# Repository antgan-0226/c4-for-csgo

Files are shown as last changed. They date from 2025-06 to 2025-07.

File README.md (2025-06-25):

# c4-for-csgo
A CSGO game C4 bomb model based on stm32.

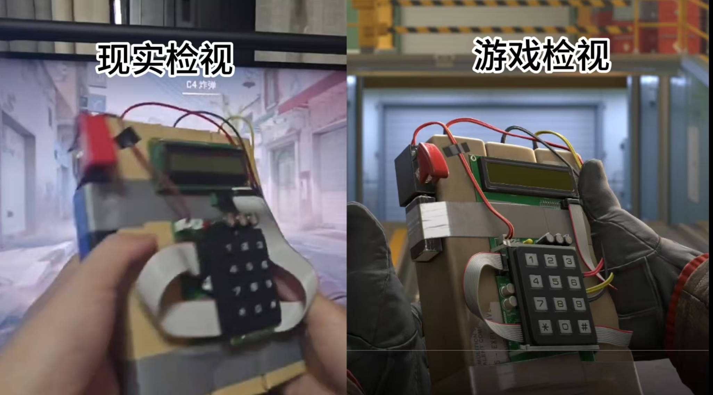
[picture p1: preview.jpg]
preview picture


**主要功能**

- 密码部署：玩家需要输入正确的密码7355608来部署 C4 炸弹，若密码错误会有相应的提示。
- 倒计时与解锁：炸弹部署成功后，开始倒计时，在倒计时期间玩家可以尝试输入解锁密码来拆除炸弹。
- 音效播放：配备 TF 卡音乐盒，在不同的状态下播放相应的音效，如部署音效、爆炸音效、MVP 音乐等。
- 状态显示：通过 LCD 屏幕显示当前的状态信息，如密码输入提示、倒计时信息、胜利提示等。
- 闹钟模式：通过按下特定按键（# 键）可进入闹钟模式。（正在做）

**免责声明:**
本项目仅为模型，不包含爆炸功能，任何改装等均不在本项目范畴中。本项目亦在还原CS2中C4炸弹的外观而非实际用途。

# 环境
- 使用Keil5环境开发stm32f103c8t6

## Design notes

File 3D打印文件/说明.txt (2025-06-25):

3D打印填充物3个190 * 40 * 43mm(长宽高)

如果你没有3D打印机，可以找我  或者找闲鱼的3D打印代打服务，给卖家说明填充10~15%即可，性价比最高
或者寻找其他方案

不要去淘宝拼夕夕找3D打印啊啊啊啊啊啊啊啊啊，60起步会被坑很多钱

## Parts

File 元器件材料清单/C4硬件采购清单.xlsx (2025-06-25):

采购价格仅供参考，具体不同店价格不一样。 整体元器件成本大概是100~120之间。如果要买其他电烙铁等工具，总成本在300左右。 如果没时间做，可以加微信: mayijun0226 可以帮忙代工，保姆级详细教程正在做，有疑问可以加微信询问。
器件 | 数量 |  | 备注 | 淘宝店家 | 价格
9V充电锂电池500mA | 1 |  | 不要用碳性电池或碱性电池！！ | 何维克电池 | 6.9
9V电池扣I型硬扣 | 1 | =DISPIMG("ID_F30DDC7D537947F4BAE9905A0A8C0E81",1) |  | zave | 3.02
3362电位器10K | 1 | =DISPIMG("ID_8B0D3E154CCE463D918A6B754BDE80D5",1) |  | zave | 3.68
NPN三极管s8050 | 2 | =DISPIMG("ID_EE3C3700D55947208426E54390F3B294",1) |  | zave | 4.11
简易牛角插座2.54mm 2*8p直针 | 1 | =DISPIMG("ID_3D62FF74ED64414888F32AC91180FFE2",1) |  | zave | 2.35
铝电解电容直插 2200uf | 3 | =DISPIMG("ID_F6F344BF5B464863AC43FE94093CC294",1) |  | zave | 3.69
XH2.54mm直针插座2P | 2 | =DISPIMG("ID_A2CB149D019C4AB29669064B79B3C5D3",1) |  | zave | 2.44
XH2.54mm排线2p30cm公头 | 2 | =DISPIMG("ID_4477A8D5127242539B20EBAD8990196A",1) | 实际用下来30cm有点长了，可以买15cm的 | zave | 3.53
有源蜂鸣器5v D=12mm | 1 | =DISPIMG("ID_0D7D1331BE1E4B7FA3E4765643F8FA4A",1) |  | zave | 2.82
HK-4100F-DC5V汇科继电器 | 1 | =DISPIMG("ID_3BB9316D591745199AFCEB55EA78C735",1) |  | zave | 3.53
KF310-4P接线柱 十字 蓝色 可拼接 | 1 | =DISPIMG("ID_3EF6C32E9268451F9E2B2C28B976A1E8",1) |  | zave | 3.92
排针2.54mm 1*9P 针长19~23mm均可 | 1 | =DISPIMG("ID_BE62D8DB6DDB46B385E3519C7CAB37A6",1) | 建议针长19~23mm，主包是21的刚刚好 | zave | 4.91
5mm圆头LED直插红色 | 1 | =DISPIMG("ID_A6C1ED3964644E9C8F6AD8B1F987F005",1) |  | zave | 5.49
220欧姆金属膜电阻 （用于led限流） | 1 |  |  | risym 旗舰店 | 2.27
10k欧姆金属膜电阻（用于三极管下拉) | 1 |  | 跟上面那个电阻在同一个链接，你可以替换成贴片的，改原理图和pcb即可 | risym 旗舰店 | 2.27
8Ω1W或8Ω2W喇叭（直径最好<30mm） | 1 | =DISPIMG("ID_752ABEF71A3C4457934C7B5C5D347EE7",1) |  | zave | 3.45
LED显示屏排线 16P 30cm | 1 |  |  | 欣薇电子科技 | 1.08
电缆0.5平方纯铜（红黑黄） | 1 |  |  | 利民达电线电缆 | 3.15
STM32F103C8T6开发板 | 1 |  | 注意焊接的左右方向 | 贝科姆旗舰店 | 6.75
ST-LINK | 1 |  |  | 深圳市轩特佳电子 | 8.8
单片机矩阵键盘3*4 | 1 |  |  | 欣薇电子科技 | 6.28
任意5v稳压模块 | 1 |  |  | 欣薇电子科技 | 1.85
mini mp3 player模块 | 1 |  |  | 捷兴泰电子 | 3.83
钮子开关 开关+大红盖 | 1 |  |  | 深圳市辉泰电器 | 7.5
LCD1601a(黄绿色) | 1 | =DISPIMG("ID_F51466F975EA4189BC218596CA256447",1) | 不要买错成1602 | 上海斯迈诺 | 5.5
银灰色PVC警示胶带 | 1 |  |  | 品尚美塑旗舰店 | 5.1
黑色PVC胶布 | 1 |  |  | 品尚美塑旗舰店 | 3.95
A4牛皮纸浅色 | 1 |  | 浅色，A4，裁切尺寸见表的最下面附录 | 书昶办公用品专营店 | 6.46
热熔胶枪 | 1 | 随便买便宜的就行 | 买便宜的，附赠胶棒最好多于5根，我用掉了五根 |  | 15.59
小容量TF卡 | 1 | =DISPIMG("ID_F34BEDC7FAAB4E029C26E063471F7568",1) |  | 森秀 | 4.99
各类焊接工具：电烙铁、焊锡丝、等等 | 1 | =DISPIMG("ID_72A3BAE1297947FE8F4B7105E580A8AE",1) |  | 德力西 | 170
 |  |  |  | 仅元器件消耗品成本（不包括工具电烙铁等） | 123.62
 |  |  |  | 总计（包含工具） | 309.21

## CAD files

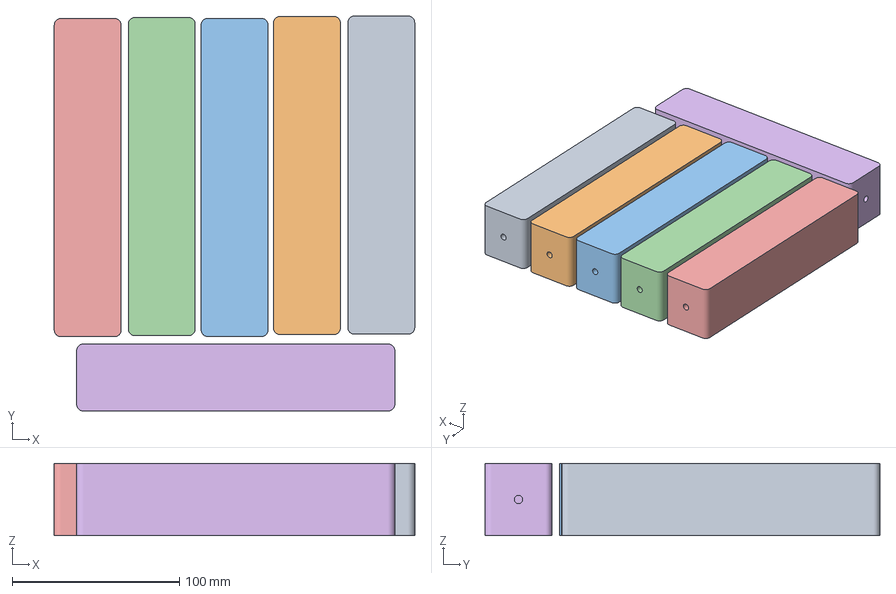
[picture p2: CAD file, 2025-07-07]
3D打印文件/c4填充物.3mf
215.3 x 235.8 x 43.0 mm
c4填充物.STL x 6

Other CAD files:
3D打印文件/c4填充物.STL

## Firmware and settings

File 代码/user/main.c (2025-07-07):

#include "stm32f10x.h"
#include "stm32f10x_flash.h"
#include "matrixkey.h"
#include "1602a.h"
#include "delay.h"
#include "LED.H"
#include "math.h"
#include "TIMER.h"
#include "Serial.h"
#include "mp3.h"
#include "string.h"
#include <stdbool.h>
#include <stdio.h> 


//函数声明
void showDefaultScreen(void);//展示默认屏幕
char arraysEqual(unsigned char arr1[], unsigned char arr2[], int size); //比较数组
void rightShiftArray(unsigned char arr[], int size);
void leftShiftArray(unsigned char arr[], int size); 
void updateKeyPressState(void);//更新按键标识
void handleKeyPressFeedback(void);//按下键盘响应
void clearPasswordArray(unsigned char pass[], int size);//清除密码
void updatePasswordDisplay(unsigned char pass[]);//更新密码展示
void showStarAnimation(void);//展示***动画
void unlockPasswordScan(unsigned char pass[]);//解锁密码扫描
void deployPasswordScan(unsigned char pass[]);//部署密码扫描 

// 状态处理函数声明
void handleInitState(void);//初始化状态
void handlePasswordInputState(void);//处理输入状态
void handlePasswordVerifyState(void);//验证密码状态
void handleUnlockSuccessState(void);//解锁成功，CT胜利
void handleUnlockFailureState(void);//解锁失败，T胜利，播放音乐盒
void handleAlarmClockModeState(void); //闹钟模式
void checkHashPress(void); //检查是否按下#按键

// 定义系统状态
typedef enum {
    STATE_PASSWORD_INPUT, // 密码输入状态
    STATE_PASSWORD_VERIFY,// 密码验证状态
    STATE_UNLOCK_SUCCESS, // 解锁成功状态
    STATE_UNLOCK_FAILURE, // 解锁失败状态
		STATE_ALARM_CLOCK_MODE    // 设置闹钟状态
} SystemState;

// 变量定义
SystemState currentState = STATE_PASSWORD_INPUT;  // 当前系统状态
uint8_t volumeLevel = 20; // 音量级别

unsigned char defaultPassword[8]={'7','3','5','5','6','0','8'};	//默认密码
unsigned char password[8]={'*','*','*','*','*','*','*'};	//用户输入的密码
unsigned char unlockPassword[8]={'*','*','*','*','*','*','*'};	//解锁输入的密码

char KeyNum, sign; //按键变量
int unlockArrayIndex=0; //解密时密码下标
int spaceCount=5; //居中显示前面空格数
uint8_t isPressed=0; //是否键盘被按下标记
uint8_t hashPressed = 0;               // #键按下标志
uint16_t hashTimer = 0;             // 记录按#计数器
uint16_t countdown = 100;              // 倒计时值
uint16_t Num = 0,Num_sign = 0;			//定义在定时器中断里自增的变量

int main()
{
	//初始化
	mp3_Init();//mp3初始化		
	Timer_Init();//定时器初始化
	LED_Init();//led 蜂鸣器 继电器io口初始化
	LCD_INIT();		//LCD1601初始化
	MatrixKey_Init();//矩阵键盘初始化
	
	Delay_ms(1000);
	
	//开机默认显示文案
	showDefaultScreen();
		
	Delay_ms(1000);

	//mp3_start();//由于市面上mini mp3模块质量参差不齐，导致上电后无法立刻检测到指令，需等段时间才能检测到
					//如果你想启用上电音效，可以尝试取消此注释，尝试是否有上电音效

	//主循环
	while(1)
	{
		KeyNum = MatrixKey_GetValue();
		// 检测#是否按下
    checkHashPress();
		
		// 根据当前状态调用相应的处理函数
    switch(currentState) {
				case STATE_PASSWORD_INPUT:
						handlePasswordInputState();
						break;
				case STATE_PASSWORD_VERIFY:
						handlePasswordVerifyState();
            break;
				case STATE_UNLOCK_SUCCESS:
            handleUnlockSuccessState();
            break;
				case STATE_UNLOCK_FAILURE:
						handleUnlockFailureState();
            break;
        case STATE_ALARM_CLOCK_MODE:
            handleAlarmClockModeState();
						break;
				default:
						currentState = STATE_PASSWORD_INPUT;
						break;
		}
		Delay_ms(10);
  }
}

// 检测#是否按下
void checkHashPress(void) {
    if (KeyNum == '#') {
        hashPressed = 1;
				hashTimer++;
    } else {
        hashPressed = 0;
    }
    
    // #超过5次判定为进入设置模式
    if (hashPressed) {
        if (hashTimer >= 5) {
            currentState = STATE_ALARM_CLOCK_MODE;
            hashPressed = 0;
        }
    } else {
        hashPressed = 0;
    }
}

// 密码输入状态处理
void handlePasswordInputState(void) {
    deployPasswordScan(password);
    
    // 检测密码是否输入完成
    if(password[0] != '*') {
        // 延时防抖
        for(long i = 0; i < 50000; i++) {
            deployPasswordScan(password);
        }
				
				//输入完毕
				//检查密码是否输入完成并与默认密码对比
				if (password[0] != '*' && password[6] != '*') {  // 假设7位密码已输入完成
						Delay_ms(200);  // 防抖延时
						if (password[0] != '*' && password[6] != '*') {  // 二次确认
								if (arraysEqual(password, defaultPassword, 7)) {
										// 密码正确，部署成功
										currentState = STATE_PASSWORD_VERIFY;
								} else {
										// 密码错误, 提示
										LCD_WRITE_StrDATA("Password Error!", 0);
										for(int i = 0; i < 5; i++) {
												LED1_Turn();
												Delay_ms(50);
										}
										LED1_OFF();
										Delay_ms(2000);
										// 清空密码数组，恢复默认文案
										clearPasswordArray(password, 7);
										currentState = STATE_PASSWORD_INPUT;
									  showDefaultScreen();
								}
						}
				}
    }
}

// 默认文案
void showDefaultScreen(void) {
		LCD_WRITE_StrDATA("                ", 0);
		LCD_WRITE_StrDATA("*******", spaceCount);									
}

// 密码验证状态处理
void handlePasswordVerifyState(void) {
    LED2_ON();
    mp3_over();
	
		for(int j=0; j<countdown; j++)//倒计时提示
		{
			LED1_ON();
		
			// 蜂鸣器和LED亮起时间
			for(int i = 0; i < 2; i++) {
				KeyNum = MatrixKey_GetValue();
				if(KeyNum!=' '){sign=1;}
			
				if(sign == 0) {
					Delay_ms(20);                    
				} else {
					unlockPasswordScan(unlockPassword);                            
				}
		}
		
		LED1_OFF();
		for(int i=0; i<((int)((pow(((double)0.978),((double)j)))*50)-2); i++)//j增大，此for循环随时间增大而执行次数变少，所占用时间变短，即LED1_ON()被执行间隔的越来越短			
		{
				KeyNum = MatrixKey_GetValue();
				if(KeyNum!=' '){sign=1;}
			
				if(sign==0)
				{
						showStarAnimation();							
				}
				else
				{
						unlockPasswordScan(unlockPassword);							
				}
		}
		
		// 检查解锁密码是否输入完成
		if(unlockPassword[6] != '*') {
				if(arraysEqual(password, unlockPassword, 7)) {
					currentState = STATE_UNLOCK_SUCCESS;
					return;
				} else {
					for (int i = 0; i < 7; i++) {
						unlockPassword[i] = '*';
					}
					unlockArrayIndex = 0;
					sign=0;
					LCD_WRITE_StrDATA(unlockPassword, spaceCount);
				}
			}
		}
		
		//全部倒计时结束，拆弹失败
    currentState = STATE_UNLOCK_FAILURE;
}


// 解锁成功状态处理
void handleUnlockSuccessState(void) {
    LCD_WRITE_StrDATA("                ", 0);
    Delay_ms(50);
    
    // 成功提示
    for(int i = 0; i < 5; i++) {
        LED1_Turn();
        Delay_ms(50);
    }
    LCD_WRITE_StrDATA(unlockPassword, spaceCount);
    
    for(int i = 0; i < 2; i++) {
        Delay_ms(300);
        LCD_WRITE_StrDATA("                ", 0);
        Delay_ms(300);
        LCD_WRITE_StrDATA(unlockPassword, spaceCount);
    }
		LCD_WRITE_StrDATA("                ", 0);
		LCD_WRITE_StrDATA("CT win!", 5);
		
    while(1) {
        LED2_ON(); // 保持继电器开启
    }
}

// 解锁失败状态处理
void handleUnlockFailureState(void) {
    LED1_ON();
    LCD_WRITE_StrDATA("                ", 0);
    mp3_boom_music();
    Delay_ms(1300);
    LED1_OFF();
    
		LCD_WRITE_StrDATA("T win!", 5);
    while(1) {
        LED2_OFF(); // 保持继电器关闭
    }
}

void mp3_stop(void)
{
    // 发送停止播放命令 (0x16)
    MP3CMD(0x16, 0);
}

// 设置模式状态处理
void handleAlarmClockModeState(void) {
		LCD_WRITE_StrDATA("                ", 0);
    LCD_WRITE_StrDATA("Alarm Clock Mode!", 0);
}

void TIM2_IRQHandler(void) // TIM2定时器中断服务函数
{
    // 检查是否发生了更新中断（计数器溢出或下溢）
    if (TIM_GetITStatus(TIM2, TIM_IT_Update) == SET)    
    {
        // 根据Num_sign的值决定计数方向
        if(Num_sign == 0)
        {
            Num ++;  // 向上计数
            TIM_ClearITPendingBit(TIM2, TIM_IT_Update);  // 清除中断标志位
            if(Num >= 13) {
                Num_sign = 1;  // 达到上限，切换为向下计数
            }
        }
        else
        {
            Num --;  // 向下计数
            TIM_ClearITPendingBit(TIM2, TIM_IT_Update);  // 清除中断标志位
            if(Num <= 0) {
                Num_sign = 0;  // 达到下限，切换为向上计数
            }
        }
    }
}

char arraysEqual(unsigned char arr1[], unsigned char arr2[], int size) 
{
    for (int i = 0; i < size; i++)
	{
        if (arr1[i] != arr2[i])
				{
            return 0; // 如果发现有不相等的元素，返回false
        }
    }
    return 1; // 所有元素都相等，返回true
}

void rightShiftArray(unsigned char arr[], int size)
{
    if (size > 0)
		{
        for (int i = size - 1; i > 0; i--)
			  {
            arr[i] = arr[i - 1]; // 将每个元素向右移动
        }
        arr[0] = '*'; // 将第一个元素设置为*
    }
}

void leftShiftArray(unsigned char arr[], int size)
{
    if (size > 0) 
		{
        for (int i = 0; i < size - 1; i++) 
			  {
            arr[i] = arr[i + 1]; // 将每个元素向左移动
        }
        arr[7] = 0; // 将最后一个元素设置为0
    }
}


/**
  * @brief 处理按键按下的LED反馈
  * @note 按键按下时LED闪烁两次
  */
void handleKeyPressFeedback() {
    LED1_Turn();
    Delay_ms(50);
    LED1_Turn();
}

/**
  * @brief 清空密码数组
  * @param pass 密码数组指针
  * @param size 数组大小
  */
void clearPasswordArray(unsigned char pass[], int size) {
    for (int i = 0; i < size; i++) {
        pass[i] = '*';
    }
}

/**
  * @brief 更新按键按下状态
  * @note 按键按下时isPressed置1，松开时置0
  */
void updateKeyPressState() {
    if (KeyNum != ' ') {
        isPressed = 1; // 按键按下
    } else {
        isPressed = 0; // 按键松开
    }
}

/**
  * @brief 更新密码显示
  * @param pass 密码数组指针
  * @note 先清空LCD显示区域，再显示更新后的密码
  */
void updatePasswordDisplay(unsigned char pass[]) {
    LCD_WRITE_StrDATA("                ", 0);
    LCD_WRITE_StrDATA(pass, spaceCount);
}


//*左右晃动动画
void showStarAnimation(void)
{
	LCD_WRITE_StrDATA("                ",0);
	LCD_WRITE_StrDATA("***", Num);		
	Delay_ms(20);
}

//扫描键盘，更新解锁密码数组并更新显示
void unlockPasswordScan(unsigned char pass[])
{
	
	// 定义局部变量存储是否需要更新显示
		KeyNum = MatrixKey_GetValue();
		if (isPressed == 0) {
			// 处理数字键输入（0-9）
			if ((KeyNum!=' ') &&(KeyNum!='*') && (KeyNum!='#')&& (isPressed == 0)) {
					// 按键防抖处理
					Delay_ms(50);
					// LED反馈
					handleKeyPressFeedback();
					pass[unlockArrayIndex] = KeyNum;//第一位为按下的键
					unlockArrayIndex++;
					if(unlockArrayIndex>=7)unlockArrayIndex=0;
					updatePasswordDisplay(pass);
			}
			// 处理退格键(*)输入
			else if (KeyNum == '*' && (isPressed == 0)) {
					// 按键防抖处理
					Delay_ms(50);
					// LED反馈
					handleKeyPressFeedback();
					unlockArrayIndex--;
					pass[unlockArrayIndex]='*';
					updatePasswordDisplay(pass);
			}
			// 处理清除键(#)输入
			else if (KeyNum == '#' && (isPressed == 0)) {
					// 按键防抖处理
					Delay_ms(50);
					// LED反馈
					handleKeyPressFeedback();
					// 清空密码数组
					clearPasswordArray(pass, 7);
					// 标记需要更新显示
					unlockArrayIndex=0;
					updatePasswordDisplay(pass);
			}
		}
    
	  // 更新按键状态
    if(KeyNum!=' ')
		{
			isPressed=1;//按下
			Delay_ms(20);
		}
		else
		{
			isPressed=0;
			Delay_ms(20);
		}
}

void deployPasswordScan(unsigned char pass[]) {
    // 获取当前按键值
    KeyNum = MatrixKey_GetValue();
    
    // 定义局部变量存储是否需要更新显示
    bool needDisplayUpdate = false;
    
    // 处理数字键输入（0-9）
    if ((KeyNum >= '0' && KeyNum <= '9') && (isPressed == 0)) {
        // 按键防抖处理
        Delay_ms(50);
        // LED反馈
        handleKeyPressFeedback();
        // 左移数组并添加新输入的数字
        leftShiftArray(pass, 8);
        pass[6] = KeyNum;
        // 标记需要更新显示
        needDisplayUpdate = true;
    }
    // 处理退格键(*)输入
    else if (KeyNum == '*' && (isPressed == 0)) {
        // 按键防抖处理
        Delay_ms(50);
        // LED反馈
        handleKeyPressFeedback();
        // 右移数组实现退格
        rightShiftArray(pass, 7);
        // 标记需要更新显示
        needDisplayUpdate = true;
    }
    // 处理清除键(#)输入
    else if (KeyNum == '#' && (isPressed == 0)) {
        // 按键防抖处理
        Delay_ms(50);
        // LED反馈
        handleKeyPressFeedback();
        // 清空密码数组
        clearPasswordArray(pass, 7);
        // 标记需要更新显示
        needDisplayUpdate = true;
    }
    
    // 更新按键状态
    updateKeyPressState();
    
    // 根据标记更新LCD显示
    if (needDisplayUpdate) {
        updatePasswordDisplay(pass);
    }

}

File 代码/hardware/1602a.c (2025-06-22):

#include "1602a.h"
#include "stm32f10x_rcc.h"

/**
 * @brief 微秒级延时函数
 * @param us 延时的微秒数
 * @note 使用嵌套循环和nop指令实现延时，精度取决于系统时钟
 */
void delay_us(unsigned int us)
{
	unsigned int  i;
	
	do
	{
		i = 10;
		while(i--) __nop();  // 空操作，延长执行时间
	} 
	while (--us);
	
}

/**
 * @brief 初始化LCD相关GPIO引脚
 * @details 配置RS、RW、EN控制引脚和数据引脚为推挽输出模式
 */
void GPIO_INIT(void)
{		
	
	GPIO_InitTypeDef PB;
	GPIO_InitTypeDef PA;
	
	GPIO_PinRemapConfig(GPIO_Remap_SWJ_JTAGDisable, ENABLE);	// 禁用JTAG，释放PA15、PB3、PB4引脚
	RCC_APB2PeriphClockCmd( RCC_APB2Periph_GPIOA, ENABLE );
	RCC_APB2PeriphClockCmd( RCC_APB2Periph_GPIOB, ENABLE );		// 使能GPIOA和GPIOB时钟
	
	
	
	PB.GPIO_Pin = EN|RW|RS; //PB12-RS   PB13-RW   PB14-EN									
	PB.GPIO_Mode = GPIO_Mode_Out_PP;  // 推挽输出模式
	PB.GPIO_Speed = GPIO_Speed_50MHz;
	GPIO_Init(GPIOB, &PB);
	
	
	
	PA.GPIO_Pin = GPIO_Pin_0|GPIO_Pin_1|GPIO_Pin_2|//LCD数据引脚
								GPIO_Pin_3|GPIO_Pin_4|GPIO_Pin_5|
								GPIO_Pin_6|GPIO_Pin_7;
	PA.GPIO_Mode = GPIO_Mode_Out_PP;  // 推挽输出模式
	PA.GPIO_Speed = GPIO_Speed_50MHz;
	GPIO_Init(GPIOA, &PA);
	
}

/**
 * @brief 初始化LCD模块
 * @details 执行LCD初始化序列，配置显示模式、清屏等
 */
void LCD_INIT(void)	//LCD初始化
{
	
	GPIO_INIT();	//GPIO的初始化，在LCD_INIT中调用确保初始化顺序
	
	GPIO_Write( GPIOA, 0x0000 );		// 初始化GPIOA和GPIOB输出为0
	GPIO_Write( GPIOB, 0x0000 );
	
	LCD_WRITE_CMD( 0x38 );// 设置8位数据接口，5*7点阵，2行显示
	delay_us(5000);
	LCD_WRITE_CMD( 0x38 );// 重复发送确保设置成功
	delay_us(5000);
	
	LCD_WRITE_CMD( 0x01 );// 清屏	
	delay_us(5000);
	LCD_WRITE_CMD( 0x06 );// 光标右移，显示不移动
	delay_us(5000);	
	LCD_WRITE_CMD( 0x0c );// 显示开，光标关，闪烁关
}

/**
 * @brief 向LCD写入命令
 * @param CMD 要写入的命令字节
 * @details 等待LCD空闲后，通过控制引脚发送命令
 */
void LCD_WRITE_CMD( unsigned char CMD )	// 写命令操作
{	
	
	ReadBusy();  // 等待LCD空闲
	GPIO_ResetBits( GPIOB, RS );  // RS=0，选择命令寄存器
	GPIO_ResetBits( GPIOB, RW );  // RW=0，写操作
	GPIO_ResetBits( GPIOB, EN );  // EN=0
	GPIO_Write( GPIOA, CMD );		// 输出命令到数据引脚	
	GPIO_SetBits( GPIOB, EN );    // EN=1，产生上升沿
	GPIO_ResetBits( GPIOB, EN );  // EN=0，产生下降沿，完成命令发送
}

/**
 * @brief 向LCD写入数据
 * @param ByteData 要写入的数据字节
 * @details 等待LCD空闲后，通过控制引脚发送数据
 */
void LCD_WRITE_ByteDATA( unsigned char ByteData )// 写数据操作
{	
	
	ReadBusy();  // 等待LCD空闲
	GPIO_SetBits( GPIOB, RS );   // RS=1，选择数据寄存器
	GPIO_ResetBits( GPIOB, RW );  // RW=0，写操作
	GPIO_ResetBits( GPIOB, EN );  // EN=0
	GPIO_Write( GPIOA, ByteData );  // 输出数据到数据引脚
	GPIO_SetBits( GPIOB, EN );    // EN=1，产生上升沿
	GPIO_ResetBits( GPIOB, EN );  // EN=0，产生下降沿，完成数据发送
}

/**
 * @brief 设置LCD光标位置
 * @param Column 列位置（0-15）
 * @details 将光标设置到指定列位置，采用特殊的地址映射方式
 *          前8列映射到第一行，后8列映射到第二行
 */
//LCD设置光标，列位置从左到右
void LCD_SetCursor(unsigned char Column)
{
	if(Column <= 7)// 第一行左半部分
	{
		LCD_WRITE_CMD(0x80|(Column));  // 设置第一行地址
	}
	else// 第一行右半部分（实际映射到第二行）
	{
		LCD_WRITE_CMD(0x80|(Column-8)+0x40);  // 设置第二行地址
	}
}

/**
 * @brief 在指定位置显示字符串
 * @param StrData 要显示的字符串指针
 * @param col 起始列位置
 * @details 从指定列开始显示字符串，每个字符显示后光标自动右移
 */
void LCD_WRITE_StrDATA( unsigned char *StrData, unsigned char col )// 显示字符串
{
	unsigned char i;

	for (i=0;StrData[i]!='\0';i++)
	{
		LCD_SetCursor(col);// 注意：每次写入字符前都设置光标位置
		LCD_WRITE_ByteDATA( StrData[i] );
		col++;
	}
	
}

/**
 * @brief 读取LCD忙标志
 * @details 将数据引脚配置为输入模式，读取忙标志位，等待LCD空闲
 *          完成后恢复数据引脚为输出模式
 */
void ReadBusy(void)// 读取忙标志，判断LCD是否空闲
{		
	
	GPIO_Write( GPIOA, 0x00ff );	
	
	GPIO_InitTypeDef p;
	p.GPIO_Pin = GPIO_Pin_7;		// 配置GPIOA的第7位
	p.GPIO_Mode = GPIO_Mode_IN_FLOATING;	// 浮空输入模式，用于读取LCD的忙标志
	p.GPIO_Speed = GPIO_Speed_50MHz;
	GPIO_Init( GPIOA, &p );
	
	GPIO_ResetBits( GPIOB, RS );//RS置低，选择命令寄存器
	GPIO_SetBits( GPIOB, RW );//RW置高，读操作
	
	GPIO_SetBits( GPIOB, EN );	// 使能信号置高
	while( GPIO_ReadInputDataBit( GPIOA, GPIO_Pin_7 ) );	// 读取第7位，等待忙标志为0
	GPIO_ResetBits( GPIOB, EN );// 使能信号置低
		
	p.GPIO_Pin = GPIO_Pin_0|GPIO_Pin_1|GPIO_Pin_2|
							 GPIO_Pin_3|GPIO_Pin_4|GPIO_Pin_5|
					 		 GPIO_Pin_6|GPIO_Pin_7;		// 恢复GPIOA为输出模式
	p.GPIO_Mode = GPIO_Mode_Out_PP;
	p.GPIO_Speed = GPIO_Speed_50MHz;
	GPIO_Init( GPIOA, &p  );
}

/**
 * @brief 自定义字符写入CGRAM
 * @param pos 自定义字符位置（0-7）
 * @param ImgInfo 字符点阵数据指针
 * @details 将自定义字符的点阵数据写入LCD的CGRAM
 */
void WUserImg(unsigned char pos,unsigned char *ImgInfo){ // 写入自定义字符
	unsigned char cgramAddr;			// CGRAM地址
	
	if( pos <= 1 ) cgramAddr = 0x40;		// 
	if( pos > 1 && pos <= 3 ) cgramAddr = 0x50;
	if( pos > 3 && pos <= 5 ) cgramAddr = 0x60;
	if( pos > 5 && pos <= 7 ) cgramAddr = 0x70;

	LCD_WRITE_CMD( (cgramAddr + (pos%2) * 8) );	// 设置CGRAM地址
	
	while( *ImgInfo != '\0' )// 循环写入点阵数据
	{		
		LCD_WRITE_ByteDATA( *ImgInfo );
		ImgInfo++;
	}
}

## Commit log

2025-06-22 重构代码
2025-06-24 优化代码
2025-06-25 C4硬件采购清单
    [C4硬件采购清单.xlsx]
2025-06-25 成品预览
2025-07-07 修复小问题
    [c4填充物.3mf]
2025-07-13 补充mp3
